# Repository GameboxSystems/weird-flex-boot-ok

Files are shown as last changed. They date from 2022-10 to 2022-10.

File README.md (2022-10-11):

# weird-flex-boot-ok
Quick solder flex cable and Pi Pico carrier and flex connecting PCB for Picoboot Gamecube mod.

Picoboot info can be found here: https://github.com/webhdx/PicoBoot

Webhdx has publically stated that the pins for Picoboot installation may change down the line to accommodate new features. Weird flex boot OK will be updated accordingly.

Big thank you to webhdx for their hard work on the Picoboot mod!

## PCB Build Specifications
PCB eagle files and gerbers are in the PCB folder. PCB thickness shall be 1.6mm.

BOM:

* J1 - 5 pin 1.0mm pitch FFC connector - TE Electronics - PN: 84952-5
* S1 - Slide switch SPST - CW Industries - PN: GF-123-0054

## QSB Flex Build Specifications
QSV Flex eagle files and gerbers are in the QSB-Flex folder. Flex cable thickness shall be 0.1mm with a plastic stiffner on the bottom of the flex with thickness of 0.2mm. Total thickness shall be 0.3mm with stiffner.

## Licensing
This project is licensed under GNU, feel free to do with the contents of this repo as you please. No guarantees or warranties assumed or provided.

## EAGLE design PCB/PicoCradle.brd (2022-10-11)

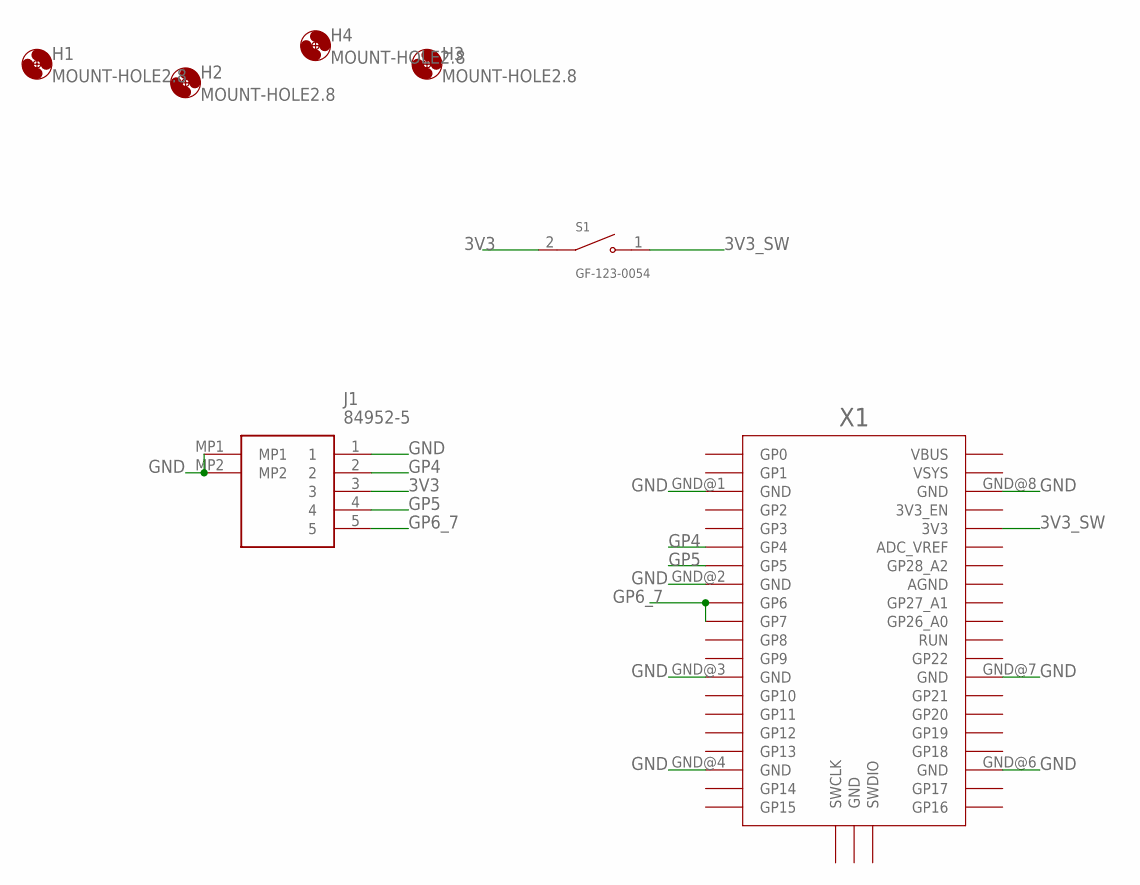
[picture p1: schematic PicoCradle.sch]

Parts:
H1, H2, H3, H4: MOUNT-HOLE2.8; 2,8
J1: 84952-5; 849525
S1: GF-123-0054; SW_GF-123-0054
X1: RPI_PICO_IG-SMD; RPI_PICO

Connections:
3V3: J1.3, S1.2
3V3_SW: S1.1, X1.3V3
GND: J1.1, J1.MP1, J1.MP2, X1.GND@1 (GND), X1.GND@2 (GND), X1.GND@3 (GND), X1.GND@4 (GND), X1.GND@6 (GND), X1.GND@7 (GND), X1.GND@8 (GND)
GP4: J1.2, X1.GP4
GP5: J1.4, X1.GP5
GP6_7: J1.5, X1.GP6, X1.GP7

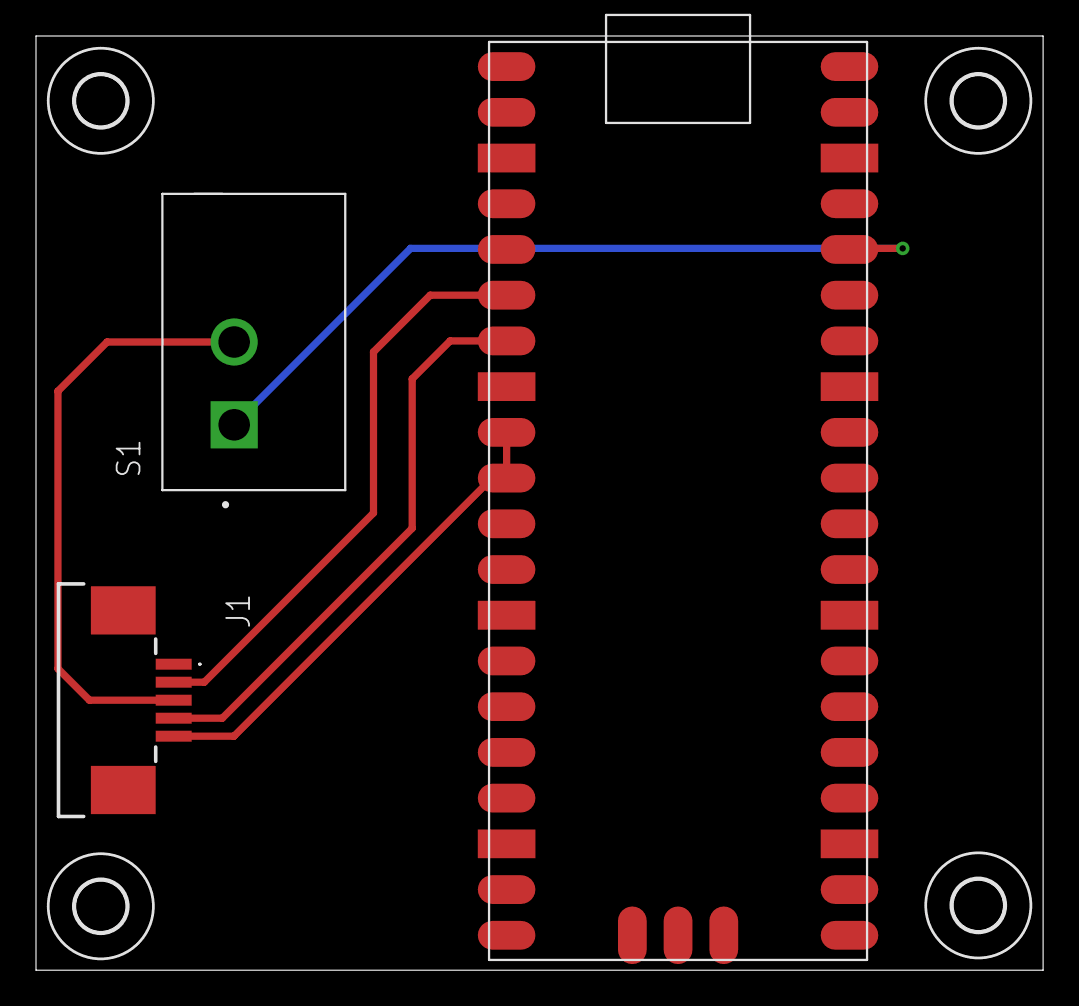
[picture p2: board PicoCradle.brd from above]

Board: 2 copper layers, 56.0 x 51.9 mm, 8 parts (1 on the bottom side), 6 nets.

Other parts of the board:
U$1: SCREENSHOT_FROM_2022#08#13_22#09#53#PNG

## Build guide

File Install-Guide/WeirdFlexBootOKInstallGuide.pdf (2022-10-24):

# Weird Flex Boot OK Install Instructions

1. Install the Picoboot firmware onto your Raspberry Pi Pico and the swiss .iso file on either an SD2SP2 or SD Gecko adapter. You can find the official tutorial to do these required steps here: https://github.com/webhdx/PicoBoot/wiki/Installationguide (https://github.com/webhdx/PicoBoot/wiki/Installation-guide)
2. After your Pico is prepped, disassemble your GameCube down to the bare motherboard without the heatsink to access the IPL IC for the flex install.
3. Line up and solder the weird flex cable to the IC as shown below.

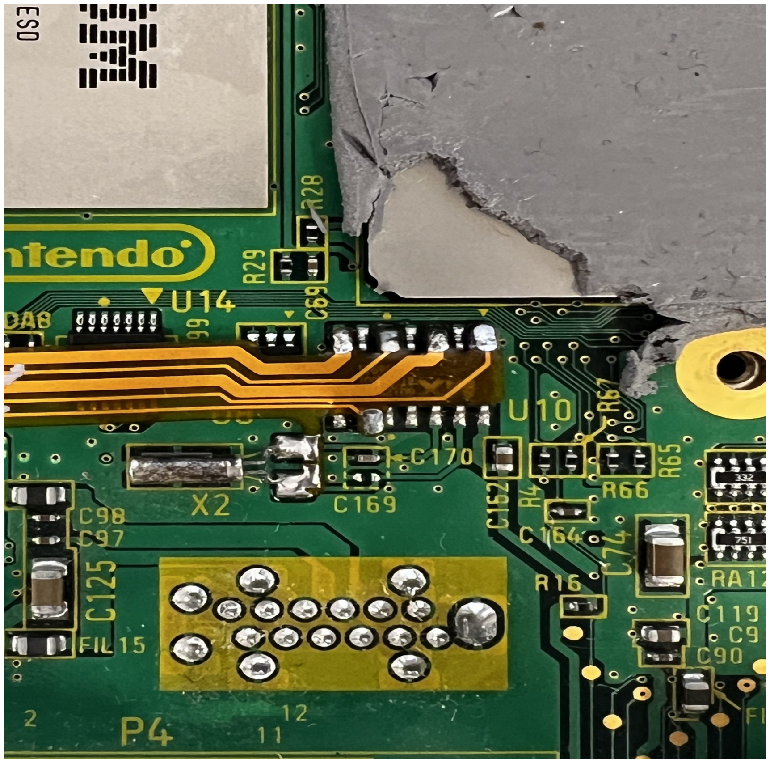
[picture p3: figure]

4. Remove the screws on the bottom of the DVD drive to detach the metal shielding from the DVD drive.

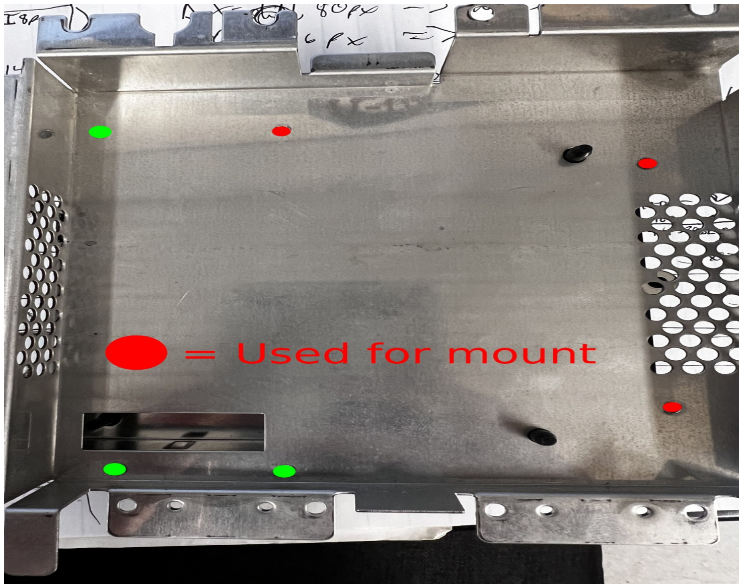
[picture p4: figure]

5. Line up the included bracket to the screw holes, positioning the bracket on the left side of the top of the shielding as shown. Fasten down using the 4x included black screws

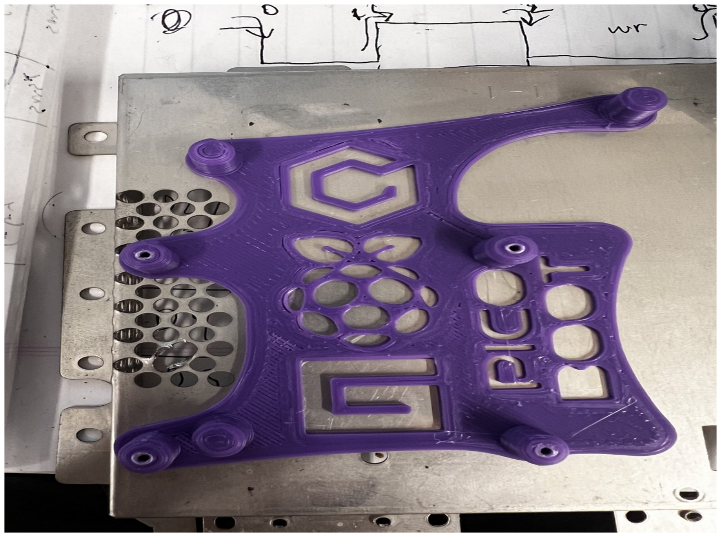
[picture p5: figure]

6. Solder your Pi Pico to the carrier board by lining it up with the silkscreen. Solder all connections to ensure the Pi Pico is securely on the PCB. NOTE: Switch Position top = off, no power to pico (used for updating pico with new firmware, Position bottom = on)

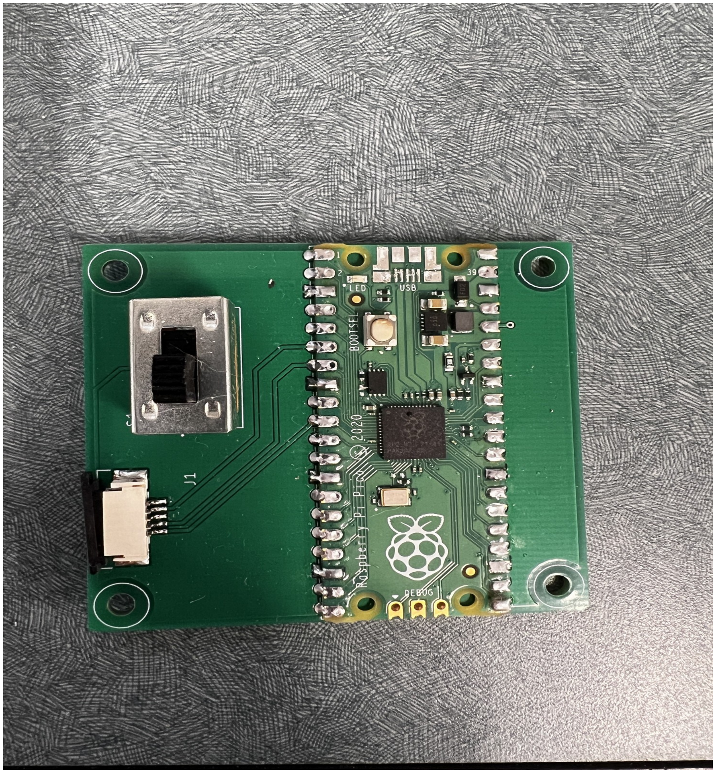
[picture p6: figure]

7. Use the DVD drive screws to fasten the Pi Pico to the DVD drive mount.

8. Replace completed DVD shield and insert the flex with pins face down.

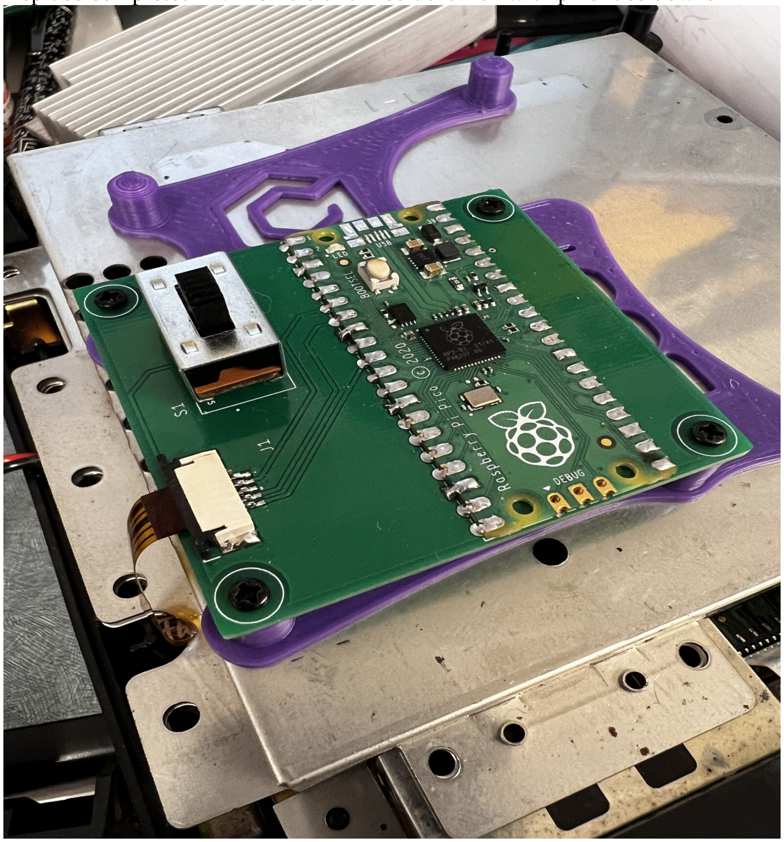
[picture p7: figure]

9. Test the install. If the install was successful, you should boot directly into swiss. 10.Reassemble the GameCube
